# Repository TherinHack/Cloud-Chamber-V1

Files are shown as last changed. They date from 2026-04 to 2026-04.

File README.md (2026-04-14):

# Cloud-Chamber-V1
Design a small Cloud Chamber using a vertical CPU cooler that can be used to show the radioactive decay of various isotopes using super cooled isopropyl alcohol.

## Cloud Chamber Full Assembely
<p align="center">
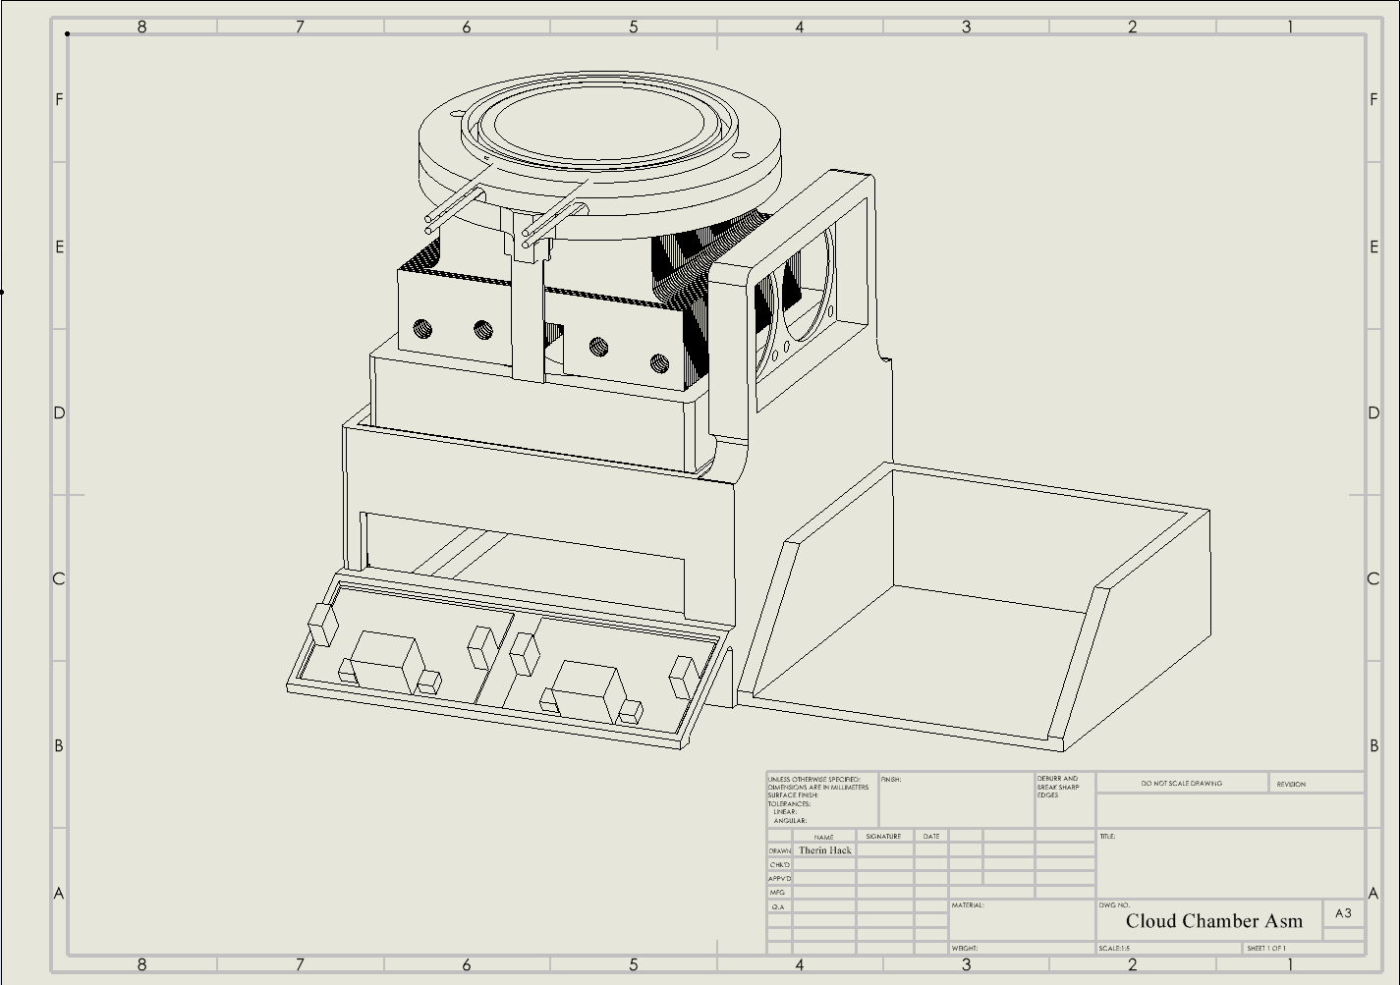
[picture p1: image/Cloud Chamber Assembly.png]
  
</p>
  - Full rendered assembely of the cloud chamber including 3d renders of the CPU cooler, Peltier's and Buck Converters.

## Cloud Chamber Stand
<p align="center">
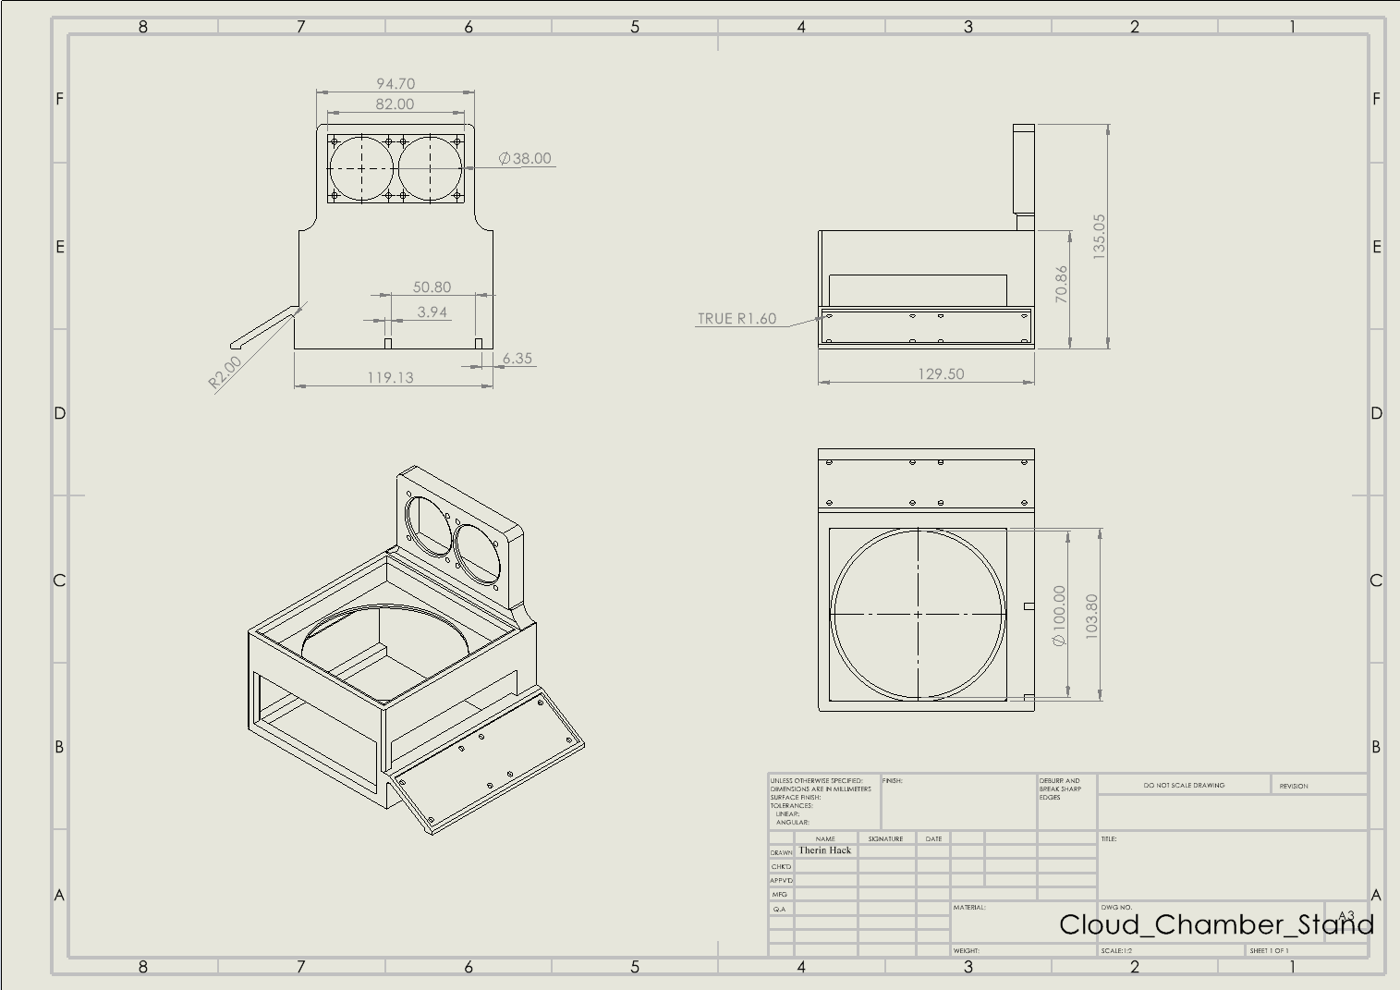
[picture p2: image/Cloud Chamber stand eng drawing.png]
  
</p>
  - The stand that the CPU cooler is seated in, with mounting space for both Buck Converters

## Cloud Chamber Lid
<p align="center">
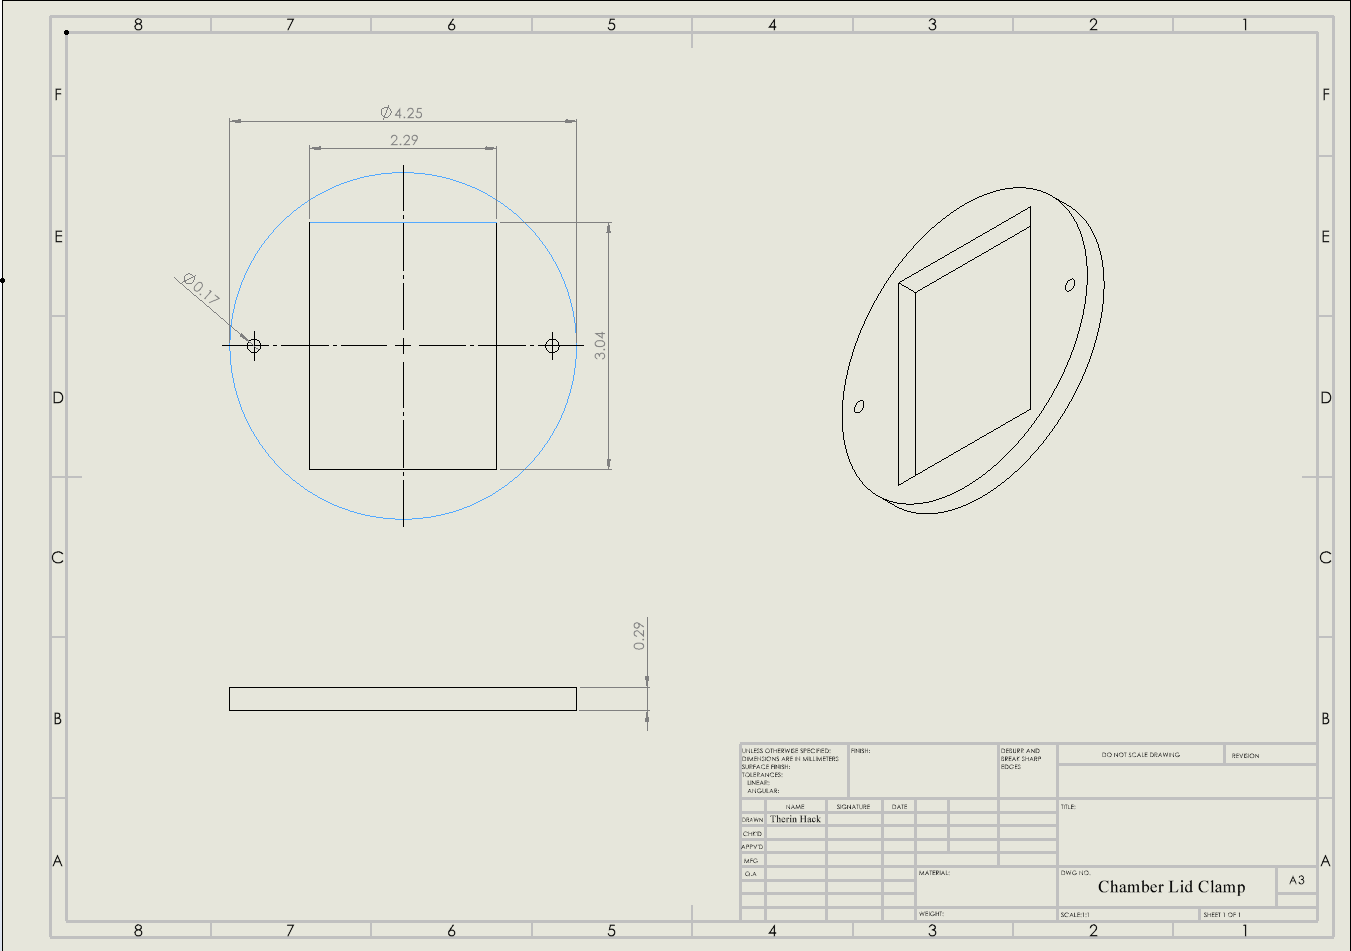
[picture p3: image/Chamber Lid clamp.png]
  
</p>
  -The bottom half of the upper clamp assembely meant to help tie the lid to the CPU cooler 

## Cloud Chamber Clamp Bottom
<p align="center">
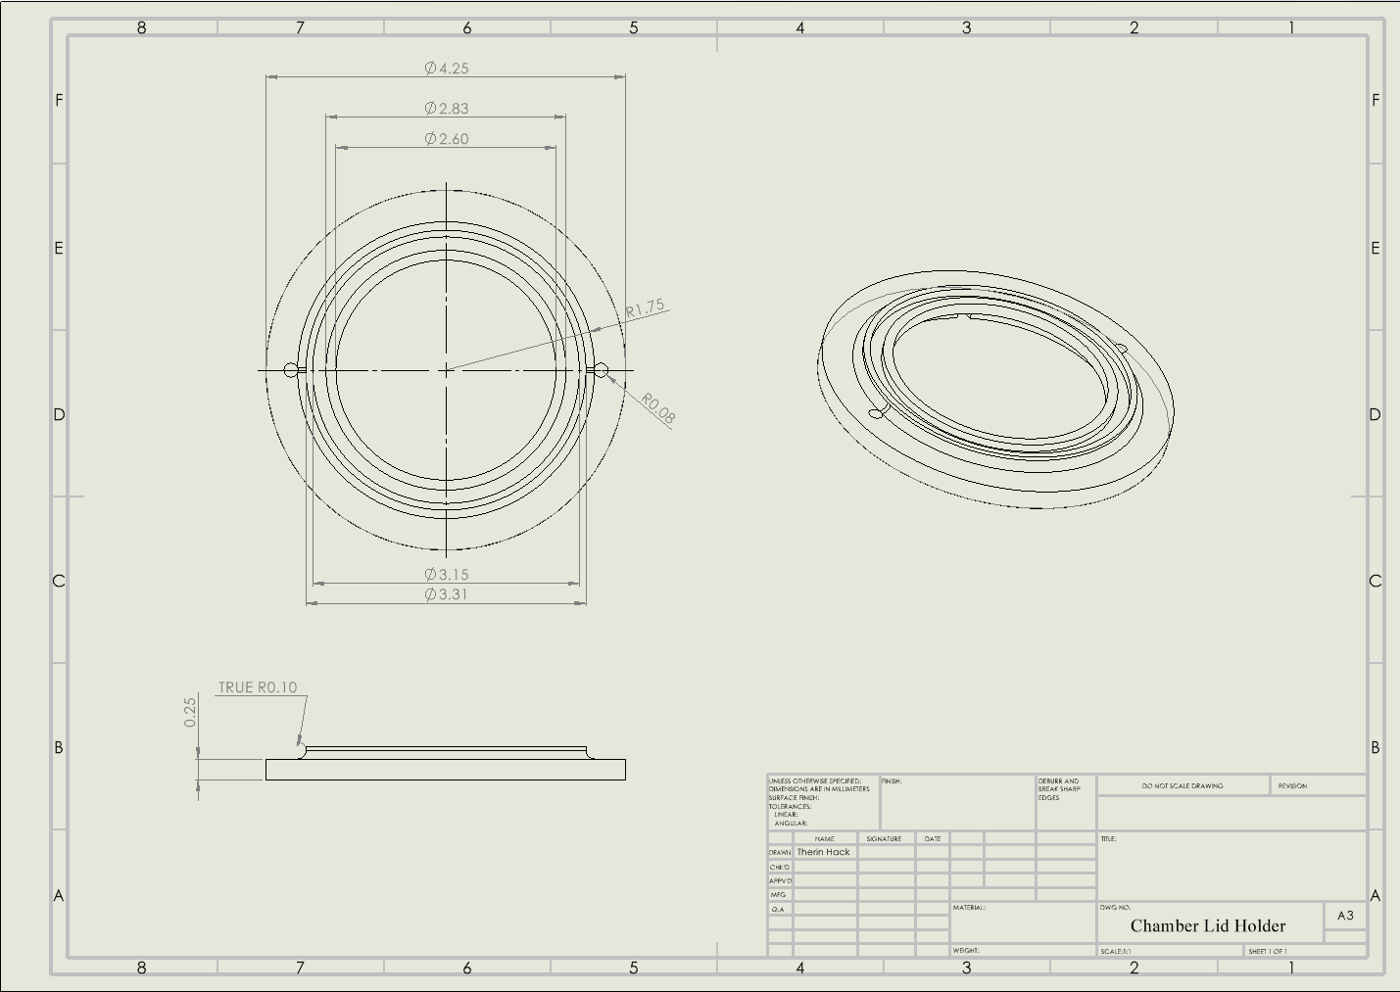
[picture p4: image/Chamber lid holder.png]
  
</p>
  - Upper half of Clamp assembely with seated groove for glass lid to nest inside of.

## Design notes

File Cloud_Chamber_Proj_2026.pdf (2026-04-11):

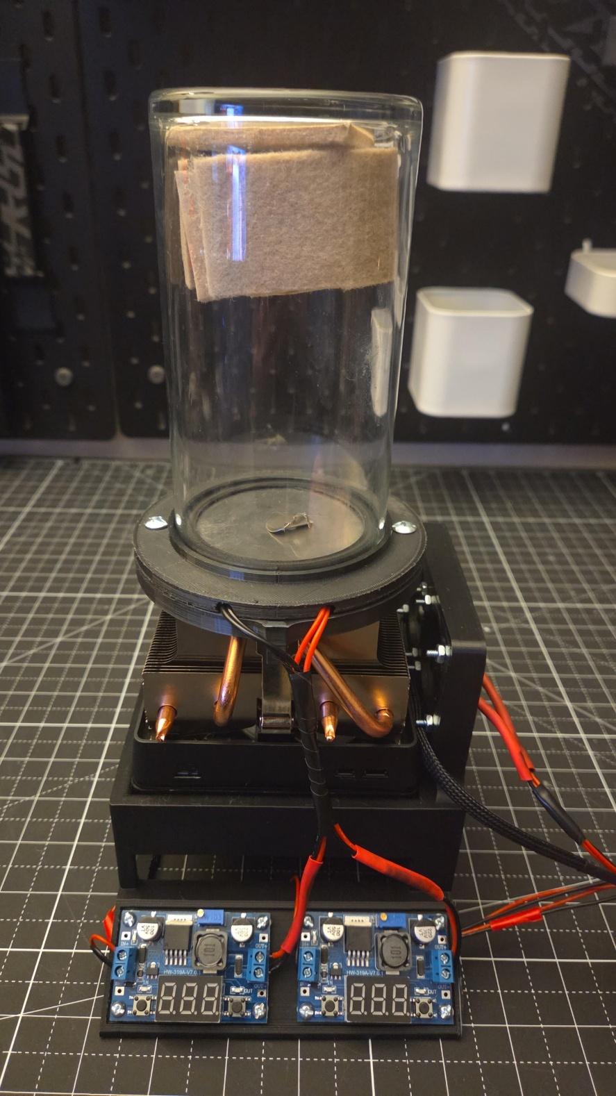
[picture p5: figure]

## Cloud Chamber Project

### Design by: Therin Hack

### Spring 2026

### Goals:

- Design a small Cloud Chamber using a vertical CPU cooler that can be used to show

the radioactive decay of various isotopes using super cooled isopropyl alcohol.

- Build a reliable project that I can use to add to my Engineering portfolio that

surrounds my interests in Design and Nuclear engineering.

### Basic Design Concepts:

- Consists of a glass viewing chamber with an aluminum plate at the bottom being

cooled by two 12v Peltier coolers, while using a CPU cooler to dissipate excess heat

out of the system to create a precise controlled environment down to around -25o

Celsius. When achieved, saturating a sponge with isopropyl alcohol will cause it to

sublimate into the encloser that when cooled down to temp, will cause the iso to

create a vapor cloud to show the alpha decay of simple radioactive isotopes.

### Possible Problems:

- Improper heat dissipation causes aluminum plate to not cool to proper temperature.
- Not properly “airtight” inside the viewing chamber, causing isopropyl to leak.
- Overdrawn power causing the Peltier’s to explode.

### Project Process:

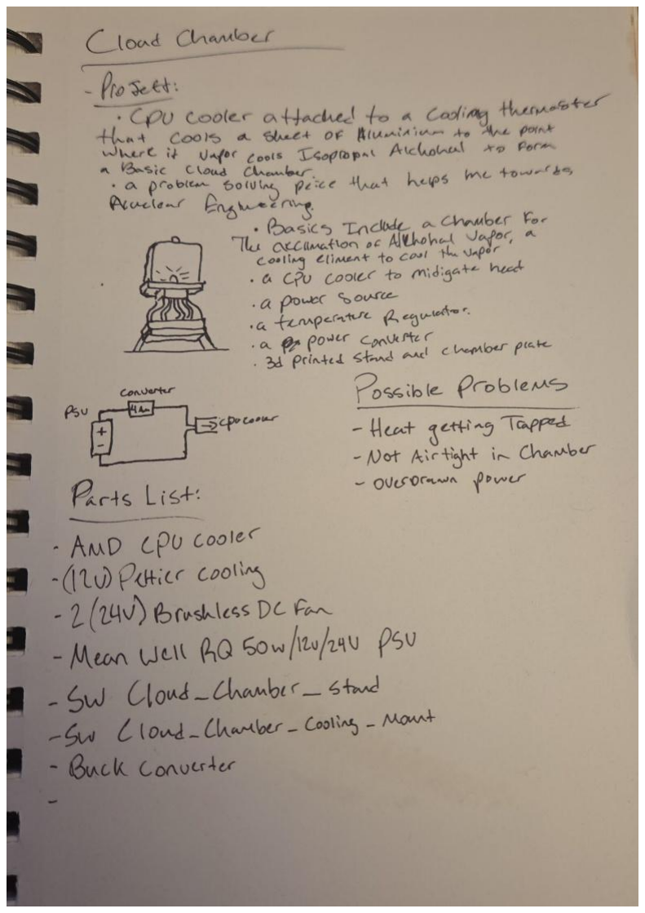
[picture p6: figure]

I started out the design of this project

on paper, writing down the plan I had for this

project with a basic parts list, simple sketch

and the concept of the project I wanted to

build (Figure 1). I then went to the Internet to

look up some basic concepts and design

choices from other engineers that had also

built their own cloud chamber concept, where

I found that the parts list for a basic cloud

chamber was fairly simple. The parts required

for this project consisted of a CPU cooler from

a PC, two 12V Peltier ceramic cooling plates,

a cylindrical glass jar, and Isopropyl alcohol.

From there I went to SolidWorks to

start the design process, since I already owned the AMD CPU cooler, I was able to get all of the

measurements for the stand for my cooler to sit in, to allow proper airflow through the system. I

also had to design a way for the glass viewing lid to sit comfortably on the top of the CPU. After

a few redesigns and tolerance fitting, I was able to test out the cloud chamber.

Figure 1 – Cloud Chamber initial concept

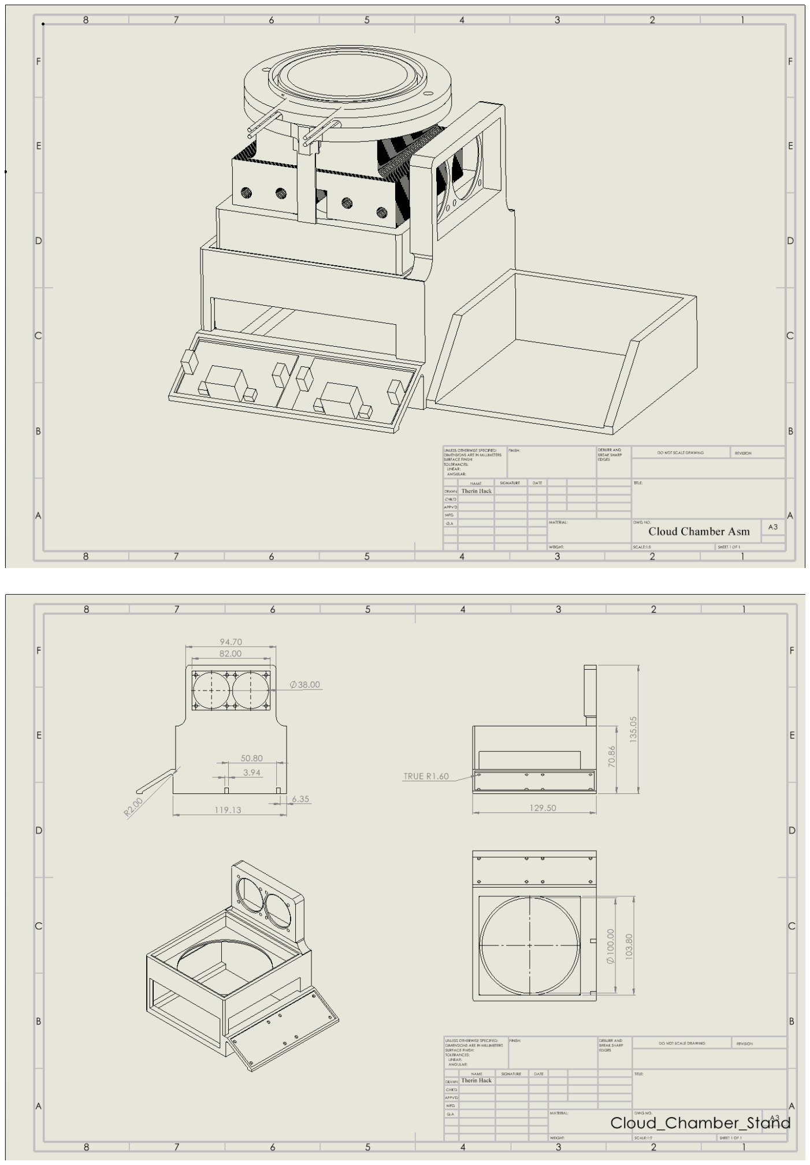
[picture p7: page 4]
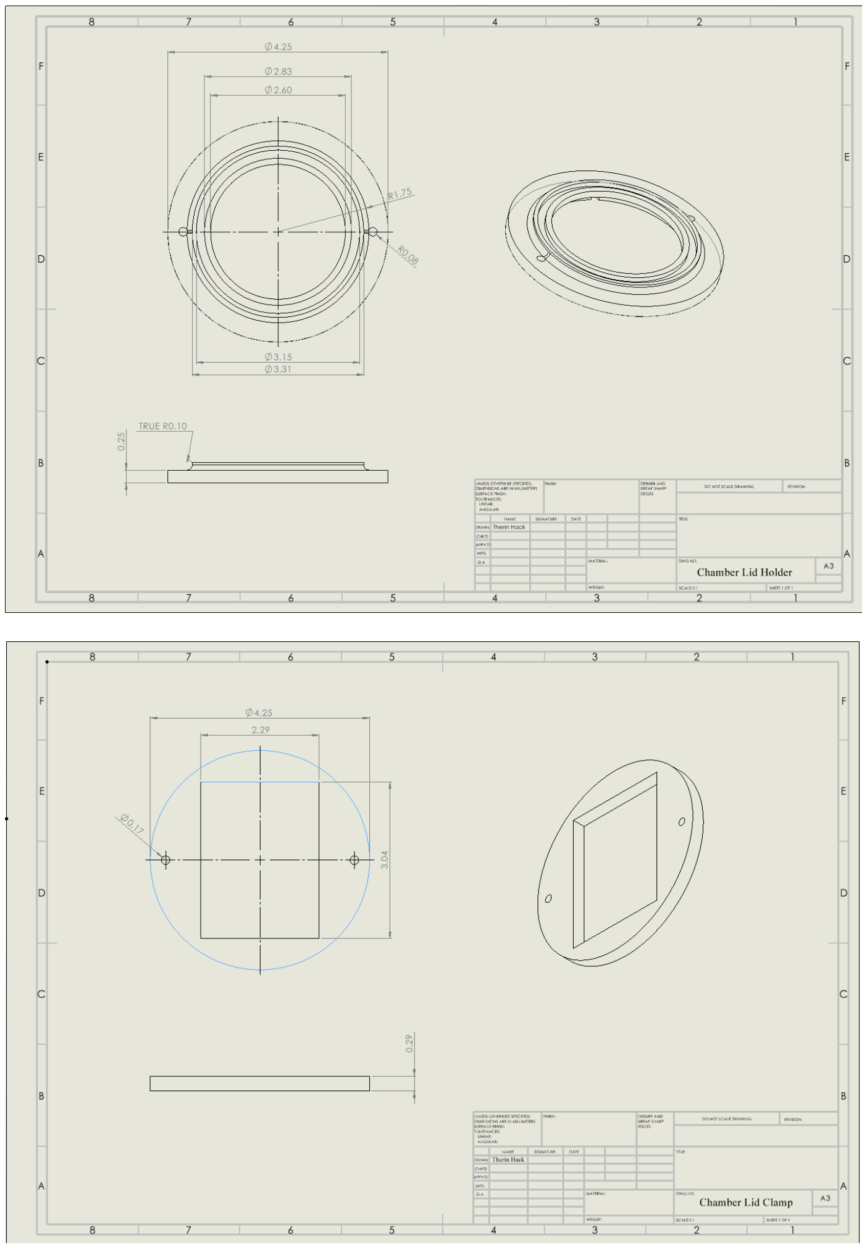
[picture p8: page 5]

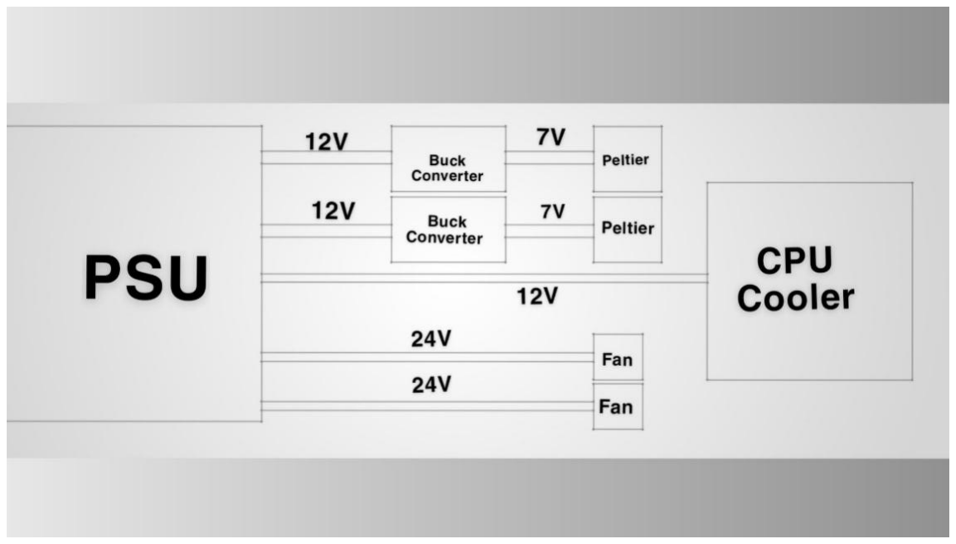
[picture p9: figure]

## Testing and Failure:

My initial test run of my cloud chamber produced very helpful results and presented a

few issues as well. One of the biggest issues being that I didn’t get any visual representation of

Beta decay off the isotope that I was using. This told me that that the issue was either: I didn’t

have enough voltage running through the Peltier’s, meaning that they weren’t able to get cold

enough, or that the chamber wasn’t airtight enough and was allowing the alcohol to escape faster

than it could cool. I decided to go back to the drawing board at this point and decided to put

more research into how much power draw and amperage the Peltier would need to reach

sufficient temperatures. What I found is that I needed to nearly double the number of AMPs that

the system could reliably handle, so that the Peltier’s could have a higher draw at 12V. Testing

after I upgraded the PSU and the Buck Converters brought the system reliably down to around

zero degrees Celsius, which was a major improvement, yet still to warm for the alcohol vapor to

condense down far enough so that the particles would show.

## To Be Continued:

Some Problems that I have encountered in this project that I intend to address and resolve

in the MRK 2 version of this project are going to be: Reaching -30 degrees Celsius, Getting a

stronger isotope, Improving airflow and cooling of the Peltier units, and redesigning the Stand to

better fit the new PSU and Buck Converters. Though this current version of the project ended in

it not working, that does not mean that this project was a failure in my eyes, just an opportunity

to improve and perfect. So, I will be coming back to this project once I can throw more hours of

research into it.

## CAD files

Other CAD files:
Cloud Clamp Draw.SLDDRW
Cloud Lid Draw.SLDDRW
Cloud_Chamber_Proj.SLDDRW
Cloud_Chamber_Stand.SLDDRW
